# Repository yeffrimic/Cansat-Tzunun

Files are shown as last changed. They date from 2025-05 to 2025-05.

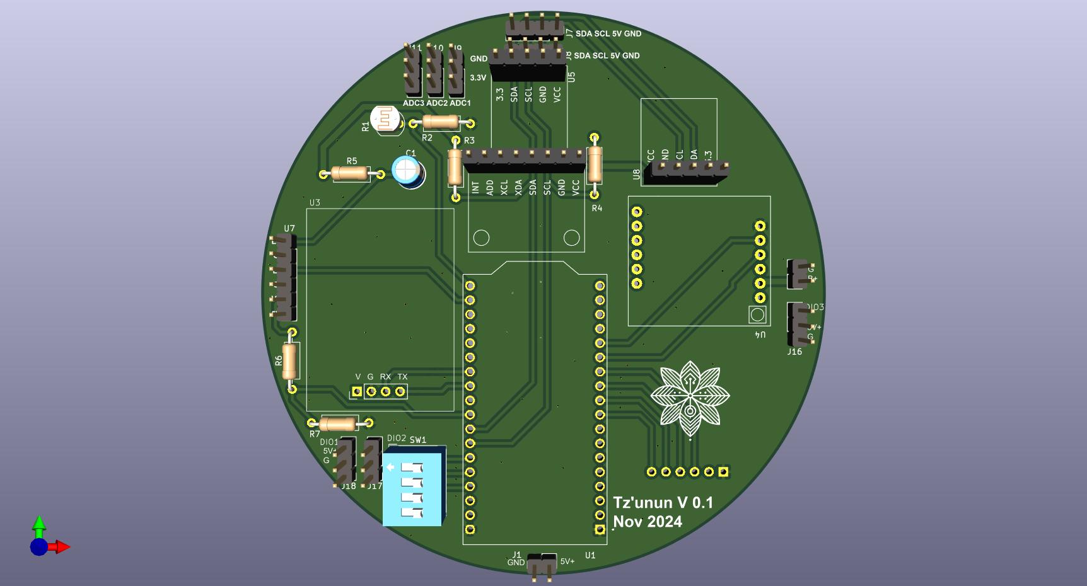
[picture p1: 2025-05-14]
kicad/frente.jpg

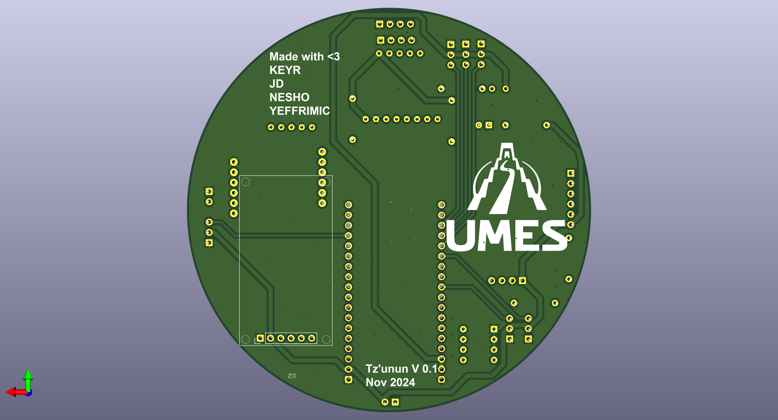
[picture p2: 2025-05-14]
kicad/back.png

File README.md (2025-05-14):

# 🌎 Estación de Calidad del Aire – Proyecto CanSat Tzunun

Este repositorio contiene el código, documentación, archivos de diseño y recursos educativos para implementar una **estación de monitoreo ambiental**, así como su versión miniaturizada adaptada al formato **CanSat**. El proyecto fue desarrollado por estudiantes de la **Universidad Mesoamericana, sede Quetzaltenango**, como una herramienta de medición ambiental portátil, educativa y de bajo costo.

---

## 🚀 Guía de Instalación – Heltec WiFi LoRa 32 (V3) en Arduino IDE

### Paso 1: Instalar el Arduino IDE
Descarga e instala la versión más reciente desde: [https://www.arduino.cc/en/software](https://www.arduino.cc/en/software)

### Paso 2: Añadir URL del Gestor de Placas
1. Abre Arduino IDE.
2. Ve a **Archivo → Preferencias**.
3. En **"Gestor de URLs adicionales de tarjetas"**, añade: https://resource.heltec.cn/download/package_heltec_esp32_index.json
### Paso 3: Instalar el soporte para Heltec
1. Ve a **Herramientas → Placa → Gestor de tarjetas**.
2. Busca **Heltec ESP32** y haz clic en *Instalar*.

### Paso 4: Seleccionar la placa correcta
1. En **Herramientas → Placa**, selecciona:  
**Heltec WiFi LoRa 32 (V3)**.
2. Configura:
- Flash Frequency: 80 MHz  
- Upload Speed: 115200  
- Partition Scheme: Default 4MB with spiffs

### Paso 5: Instalar librerías necesarias
Desde el **Gestor de Librerías**, instala:
- `Wire.h`
- `Adafruit BMP085`
- `AHTxx`
- `LoRa.h`
- `SD.h`
- `U8g2`
- Y las indicadas en la carpeta `codigo/`

---

## 📌 Descripción del Proyecto

La estación mide:
- Temperatura y humedad
- Presión atmosférica
- Gases y partículas
- Aceleración y orientación (para CanSat)
- GPS (en versiones avanzadas)

### Versiones:
- **Estación Fija:** Para instalación permanente.
- **CanSat:** Miniatura para lanzamientos simulados.

Ambas versiones transmiten datos por **LoRa/WiFi** y se visualizan con **Node-RED**.

---

## 🧠 Estructura del Repositorio

├── codigo/ # Códigos para Heltec ESP32 Lora V3

├── modelos_3d/ # Archivos STL para impresión 3D

├── node-red/ # Flujos exportados de Node-RED

├── kicad/ # Archivos del diseño PCB en KiCad

### Contenido detallado

#### `codigo/`
- Lectura de sensores
- Comunicación LoRa/WiFi
- Escritura en SD
- Pantalla OLED

#### `modelos_3d/`
- Archivos STL para impresión FDM
- Versiones fija y CanSat

#### `node-red/`
- Dashboards
- Descarga de datos (CSV, JSON)
- Endpoints y APIs

#### `kicad/`
- Archivos `.kicad_pcb`, `.sch`, `.kicad_pro`
- Gerbers, BOM y diagramas

#### `videos/`
- Armado y soldadura
- Carga de código
- Uso de Node-RED
- Diagnóstico

---

## 🧩 Hardware Utilizado

Diseño PCB en **KiCad**, optimizado para **JLCPCB** con diámetro de 10 cm.

### Componentes:
- Heltec WiFi LoRa 32 V3 (ESP32)
- GPS
- MPU6050
- BMP180
- AHT10
- Módulo GSM
- Sensor de partículas
- Conectores de expansión
- Pantalla OLED

---

## 🌐 Plataforma Node-RED

- Visualización en tiempo real
- Descarga de históricos
- Redireccionamiento automático
- Endpoints personalizados

Instalable en Raspberry Pi, PC o nube.

---

## ✅ Requisitos

- Arduino IDE
- Librerías para sensores (ver `codigo/`)
- Node-RED
- KiCad 7.x
- Fuente 5V 1A
- microSD (<8 GB) para CanSat

---

## 📄 Licencia

Este proyecto está bajo la Licencia **MIT**.  
Puedes usarlo, modificarlo y compartirlo libremente con los créditos correspondientes.

---

## 👨‍🏫 Créditos

**Universidad Mesoamericana** – Facultad de Ingeniería  
**Proyecto CanSat Tzunun 2024** – Sede Quetzaltenango  
Docente responsable: *[Nombre del asesor]*

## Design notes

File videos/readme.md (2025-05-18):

Link de los videos en google drive. 
https://drive.google.com/drive/folders/1fE3G5Yh2EopbgKv5OzK_qw8cplDIR1OE?usp=sharing

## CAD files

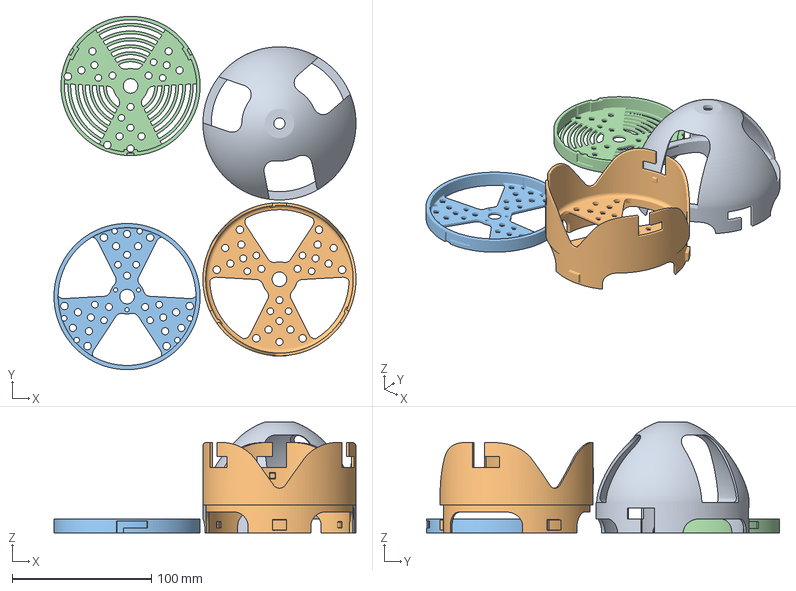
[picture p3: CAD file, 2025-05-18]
3d/Diseño_Cansat.3mf
217.0 x 253.8 x 79.7 mm
Cuerpo1 x 2
Cuerpo3
Cuerpo4

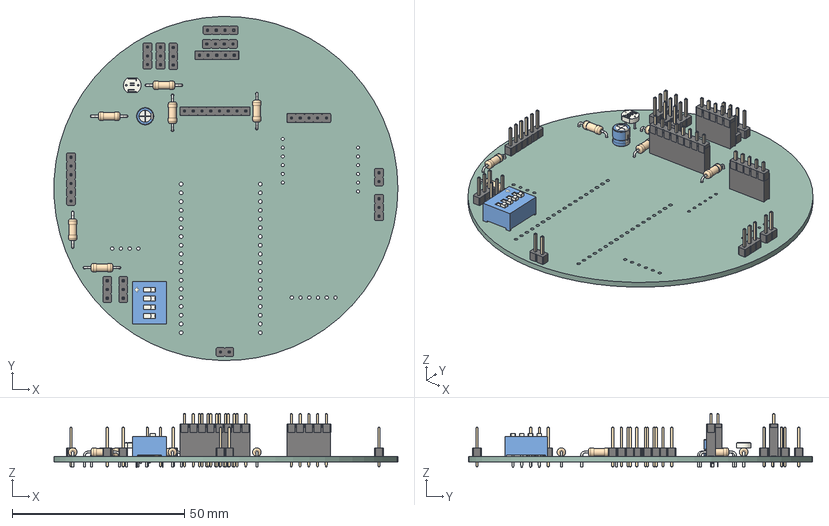
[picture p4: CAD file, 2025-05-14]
kicad/cansat.step
99.9 x 100.0 x 15.7 mm
PinSocket_1x05_P2.54mm_Vertical x 2
PinHeader_1x05_P254mm_Vertical x 2
PinHeader_1x03_P254mm_Vertical x 6
SW_DIP_SPSTx04_Slide_978x1234mm_W762mm_P254mm
R_Axial_DIN0207_L63mm_D25mm_P1016mm_Horizontal x 6
PinHeader_1x06_P254mm_Vertical
PinHeader_1x08_P254mm_Vertical
PinSocket_1x08_P2.54mm_Vertical
PinHeader_1x02_P254mm_Vertical x 2
CP_Radial_D50mm_P250mm
PinHeader_1x04_P254mm_Vertical x 2
R_LDR_5.1x4.3mm_P3.4mm_Vertical
cansat_PCB

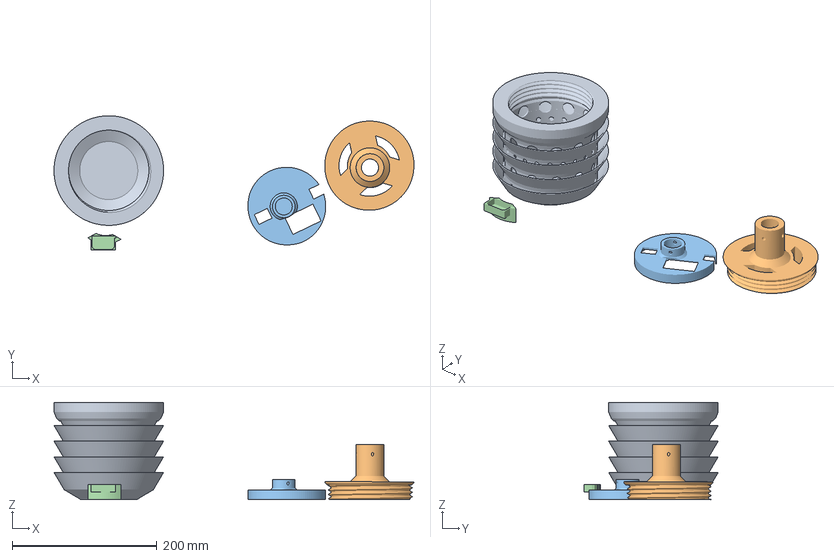
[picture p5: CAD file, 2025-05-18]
3d/Estacion_Meteorologica.3mf
497.8 x 185.9 x 134.1 mm
Cuerpo73
Cuerpo77_A
Base_Placa
Cuerpo92

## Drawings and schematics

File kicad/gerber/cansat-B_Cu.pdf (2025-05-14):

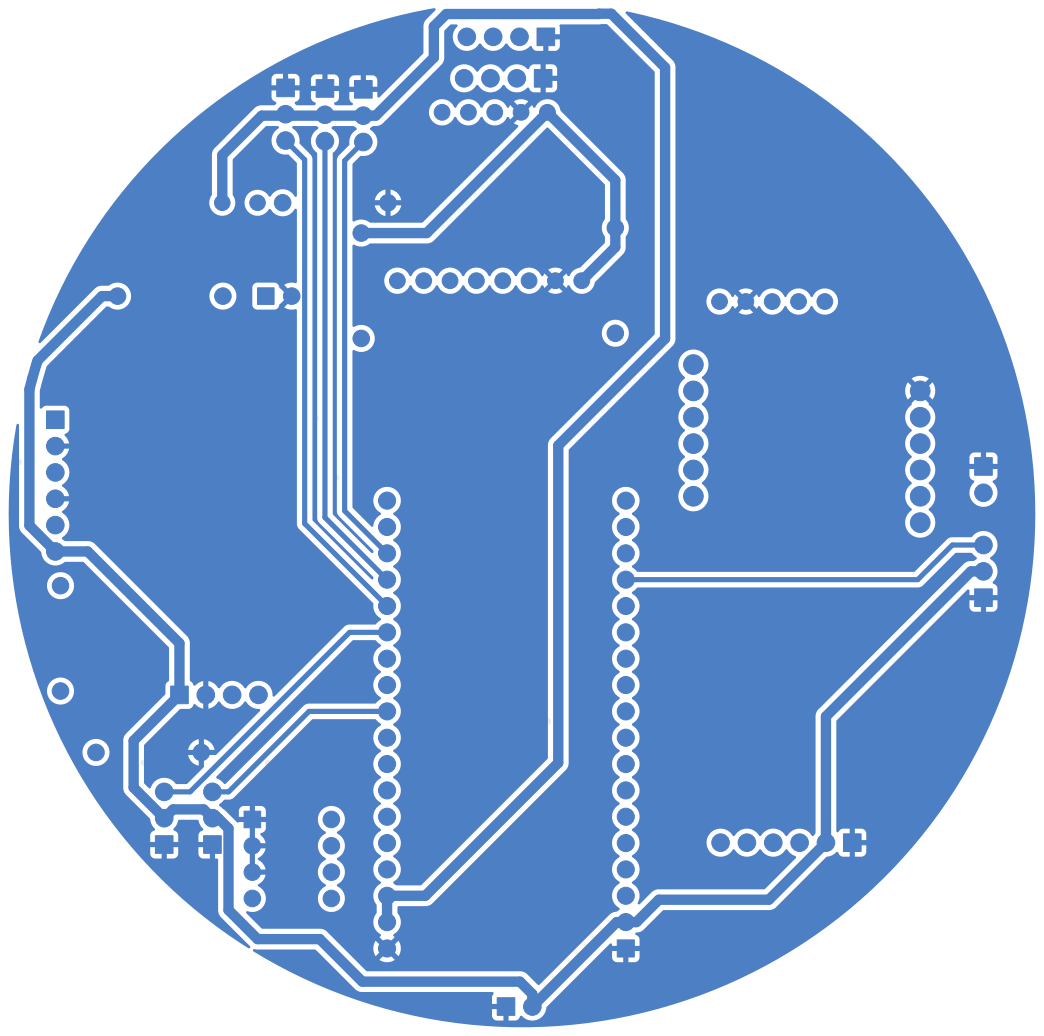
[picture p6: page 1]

Id: 1/1 Title: File: cansat.kicad_pcb Sheet:

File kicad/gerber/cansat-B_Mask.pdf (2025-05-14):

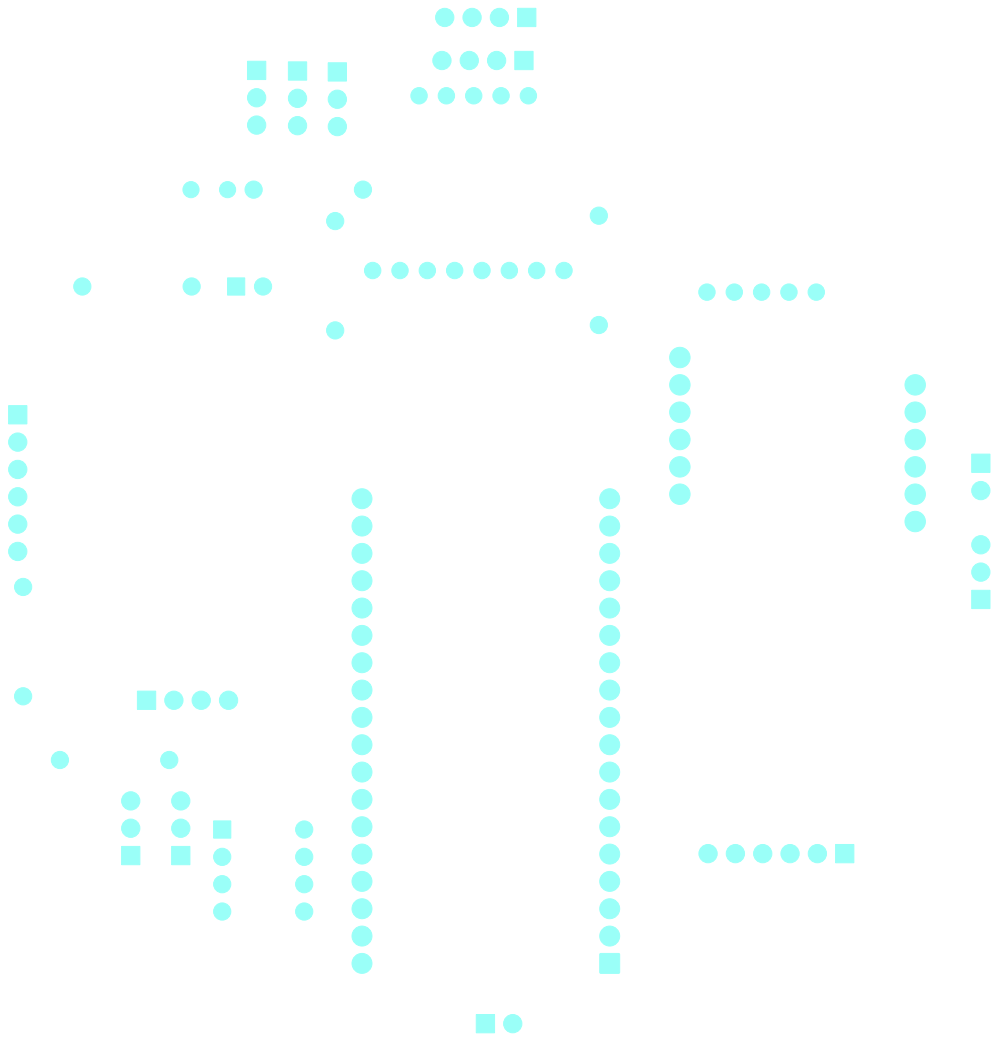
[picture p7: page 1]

Id: 1/1 Title: File: cansat.kicad_pcb Sheet:

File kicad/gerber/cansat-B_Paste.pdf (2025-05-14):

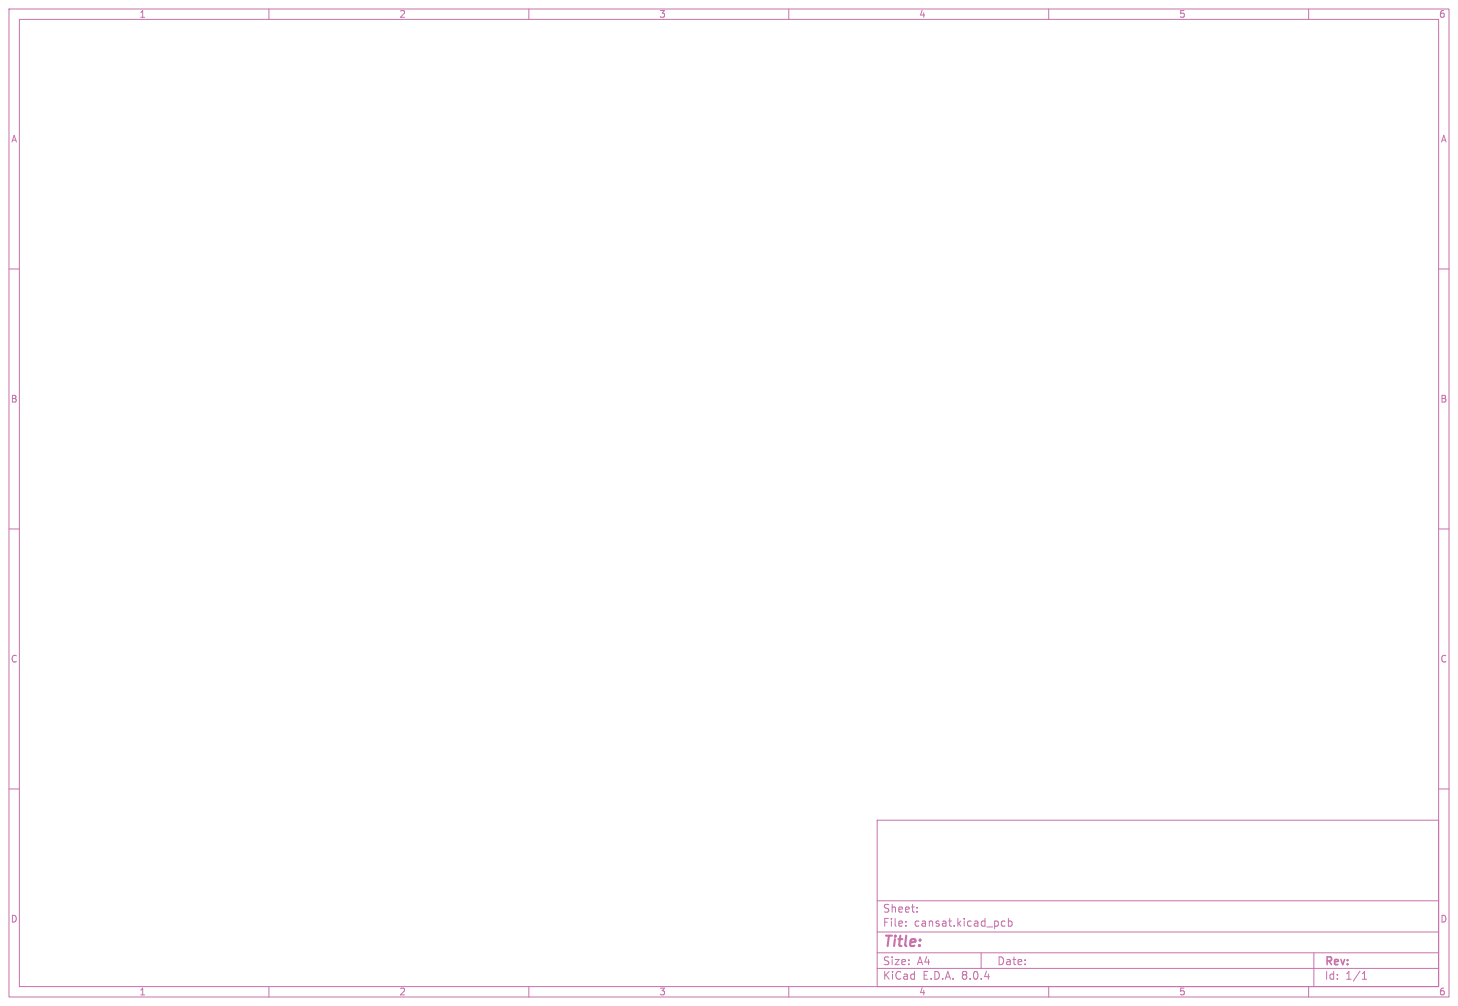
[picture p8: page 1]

Id: 1/1 Title: File: cansat.kicad_pcb Sheet:

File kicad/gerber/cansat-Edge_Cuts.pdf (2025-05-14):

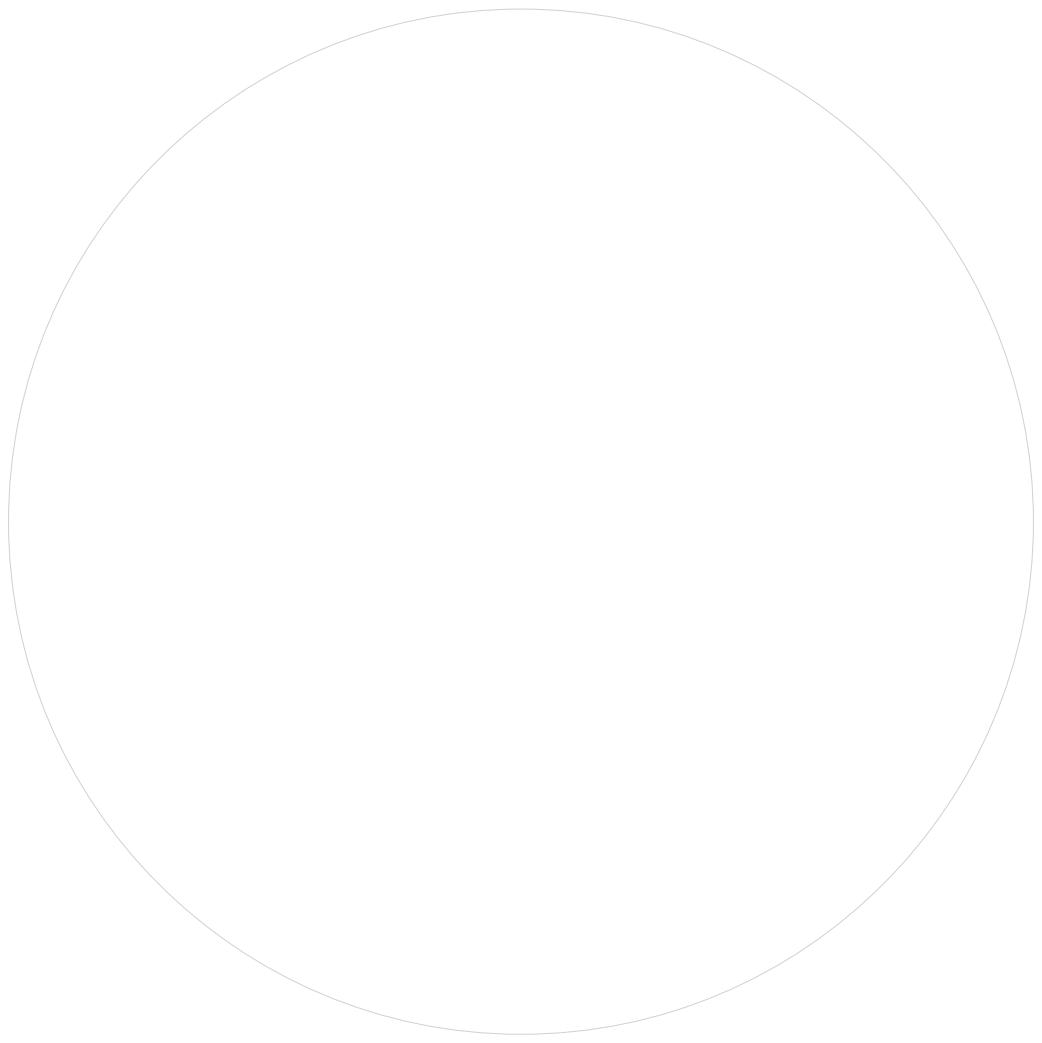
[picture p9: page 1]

Id: 1/1 Title: File: cansat.kicad_pcb Sheet:

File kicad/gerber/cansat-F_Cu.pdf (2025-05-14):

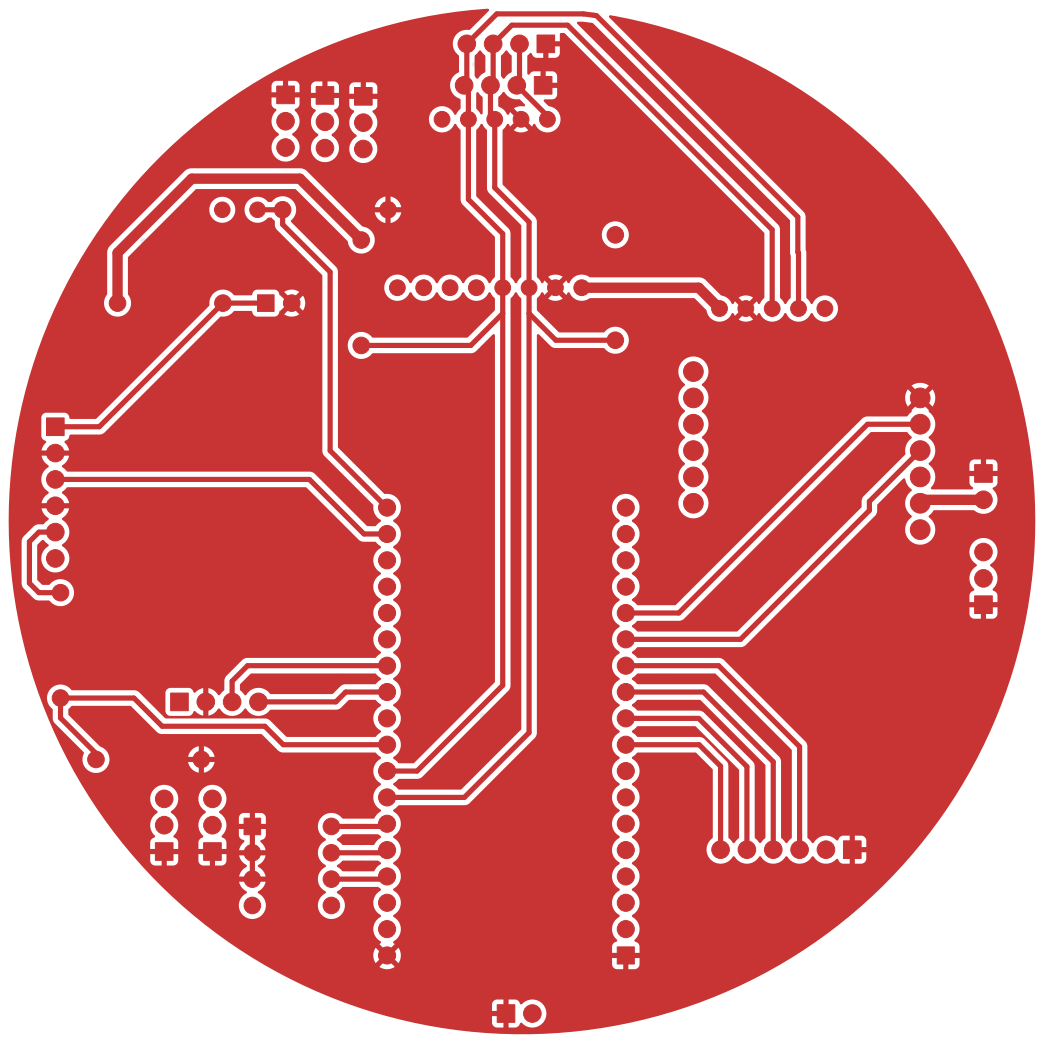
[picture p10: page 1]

Id: 1/1 Title: File: cansat.kicad_pcb Sheet:

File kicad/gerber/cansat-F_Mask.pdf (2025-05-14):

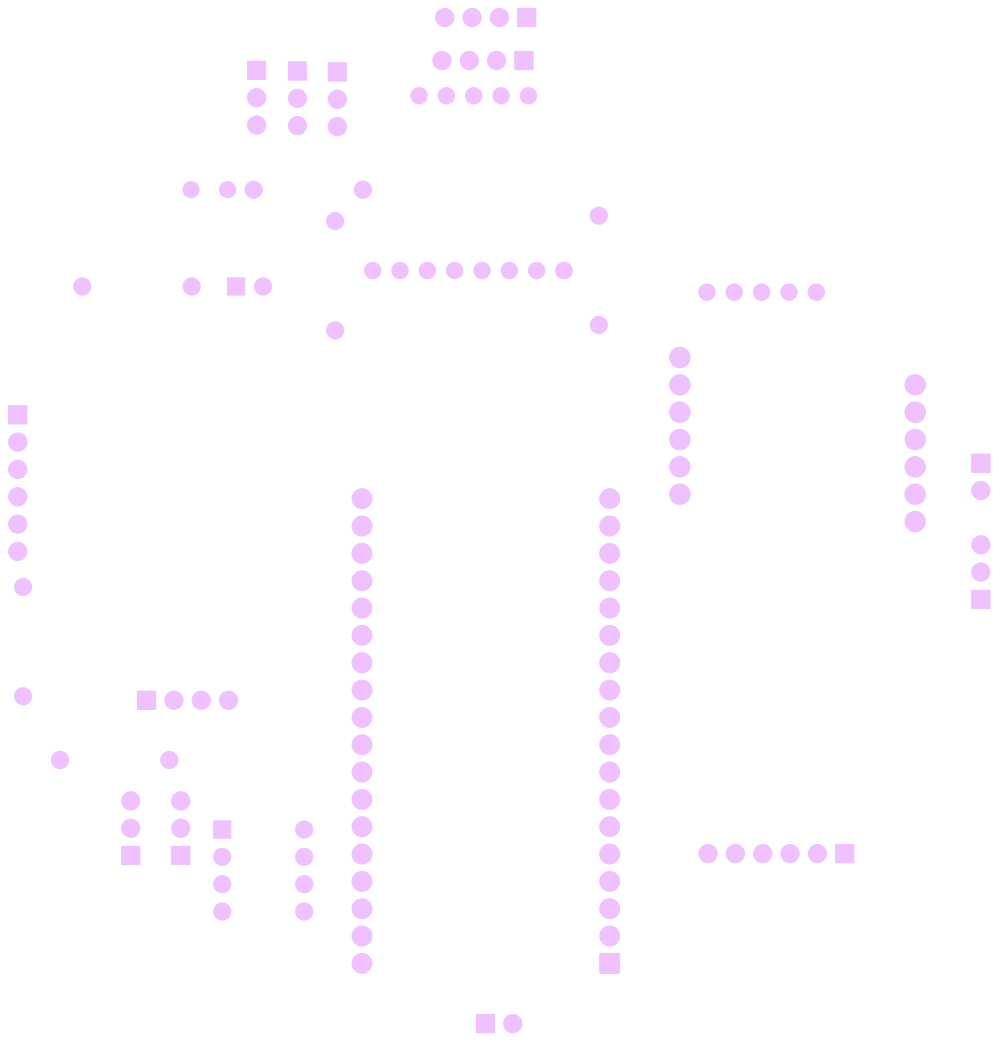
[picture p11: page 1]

Id: 1/1 Title: File: cansat.kicad_pcb Sheet:

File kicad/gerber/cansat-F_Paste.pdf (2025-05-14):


Id: 1/1 Title: File: cansat.kicad_pcb Sheet:

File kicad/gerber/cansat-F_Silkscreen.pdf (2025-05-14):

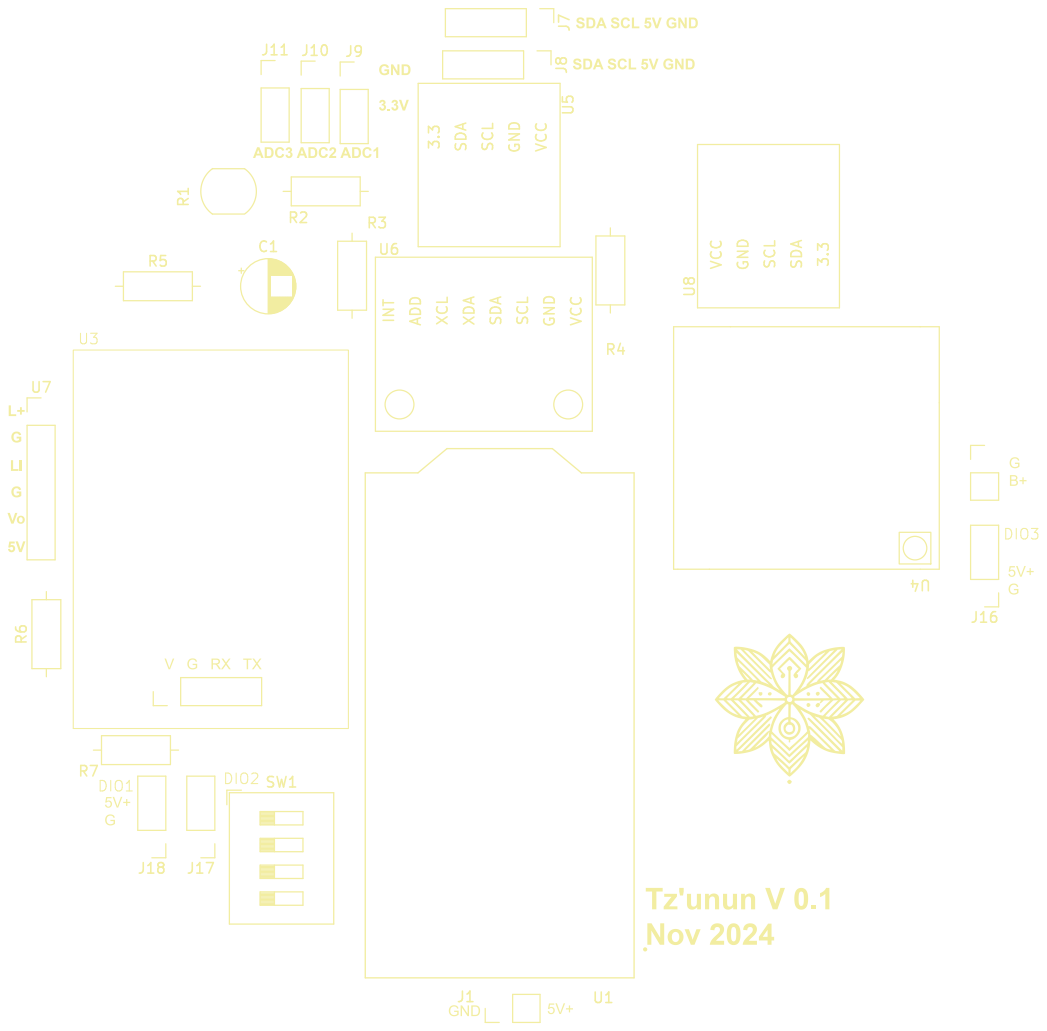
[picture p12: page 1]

U6INT ADD XCL XDA SDA SCL GND VCC

Id: 1/1 Title: File: cansat.kicad_pcb Sheet:

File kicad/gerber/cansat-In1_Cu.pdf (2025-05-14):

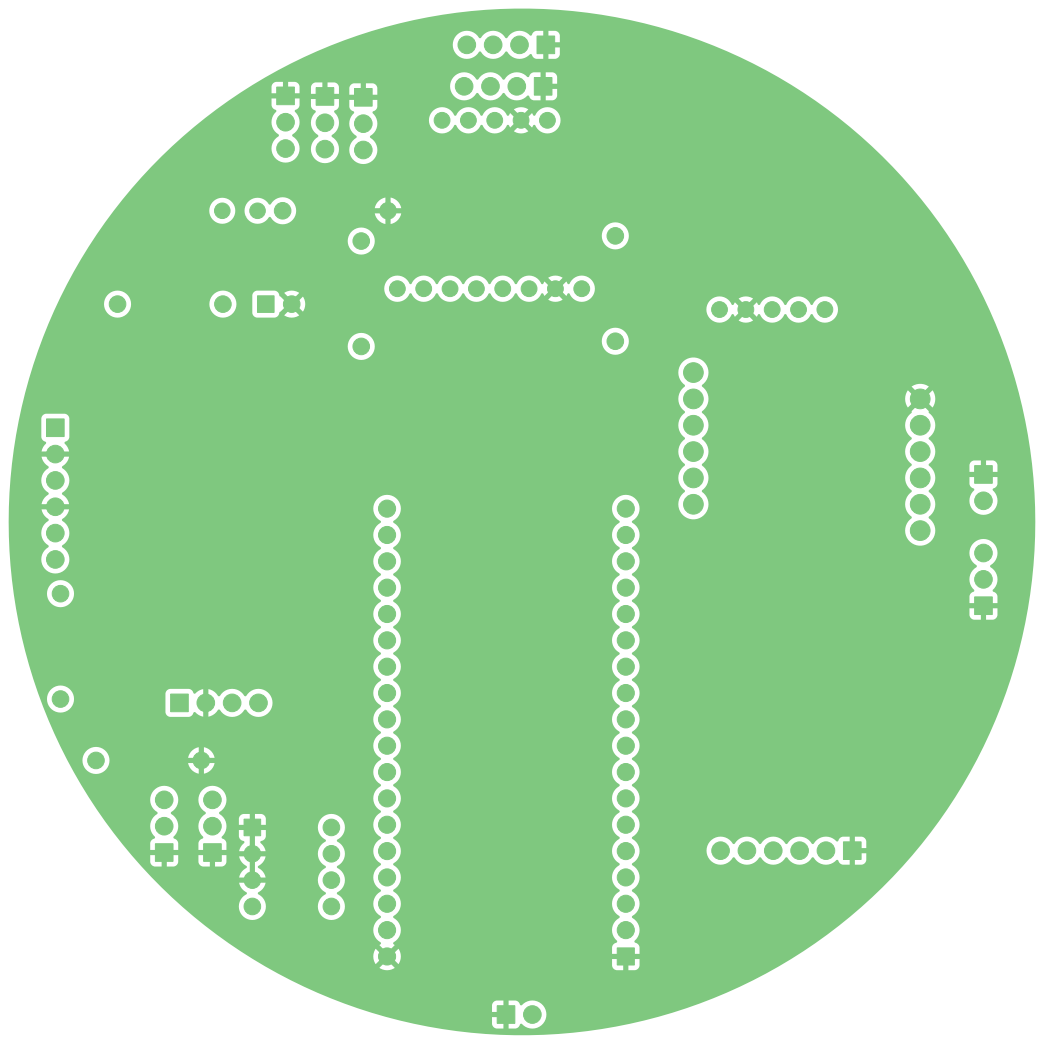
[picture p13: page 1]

Id: 1/1 Title: File: cansat.kicad_pcb Sheet:

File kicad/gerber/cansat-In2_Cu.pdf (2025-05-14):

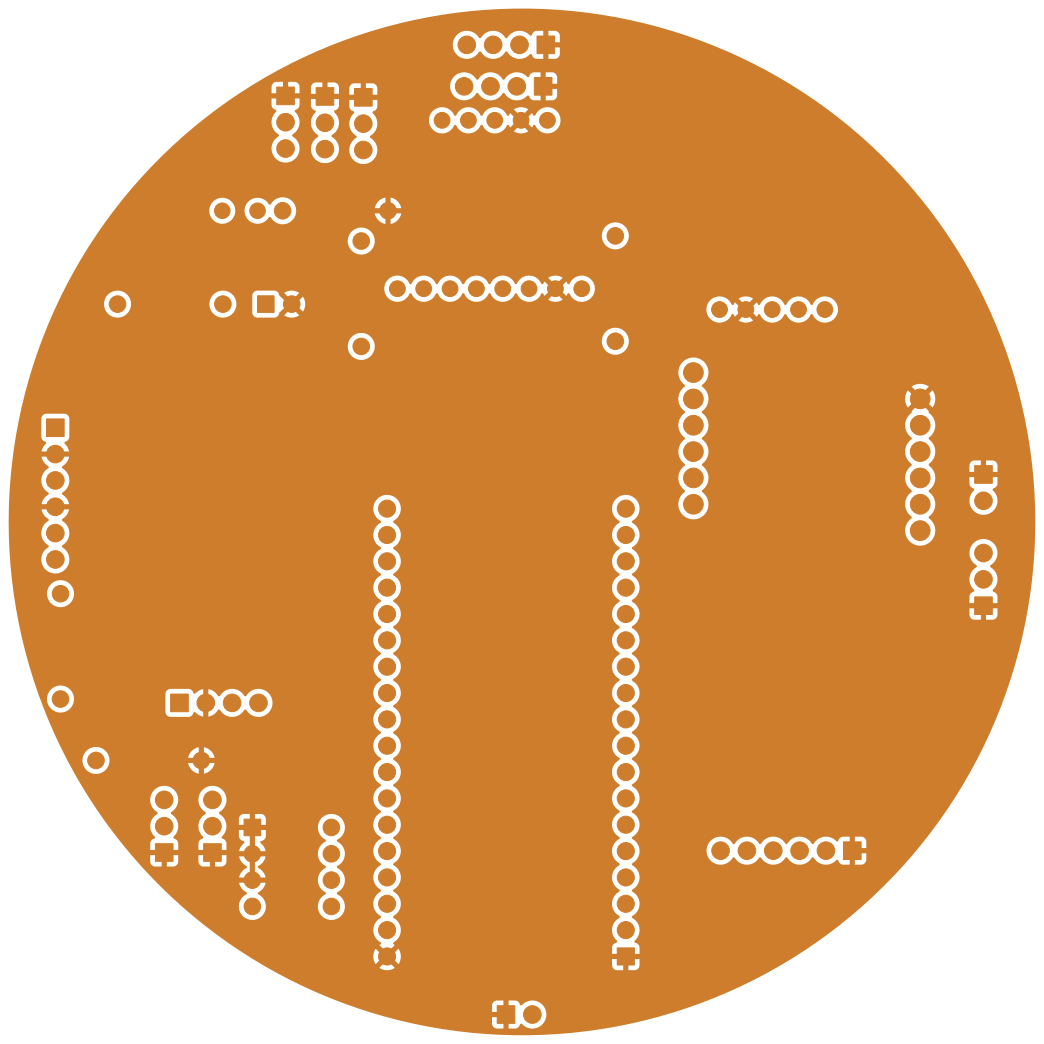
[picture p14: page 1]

Id: 1/1 Title: File: cansat.kicad_pcb Sheet:

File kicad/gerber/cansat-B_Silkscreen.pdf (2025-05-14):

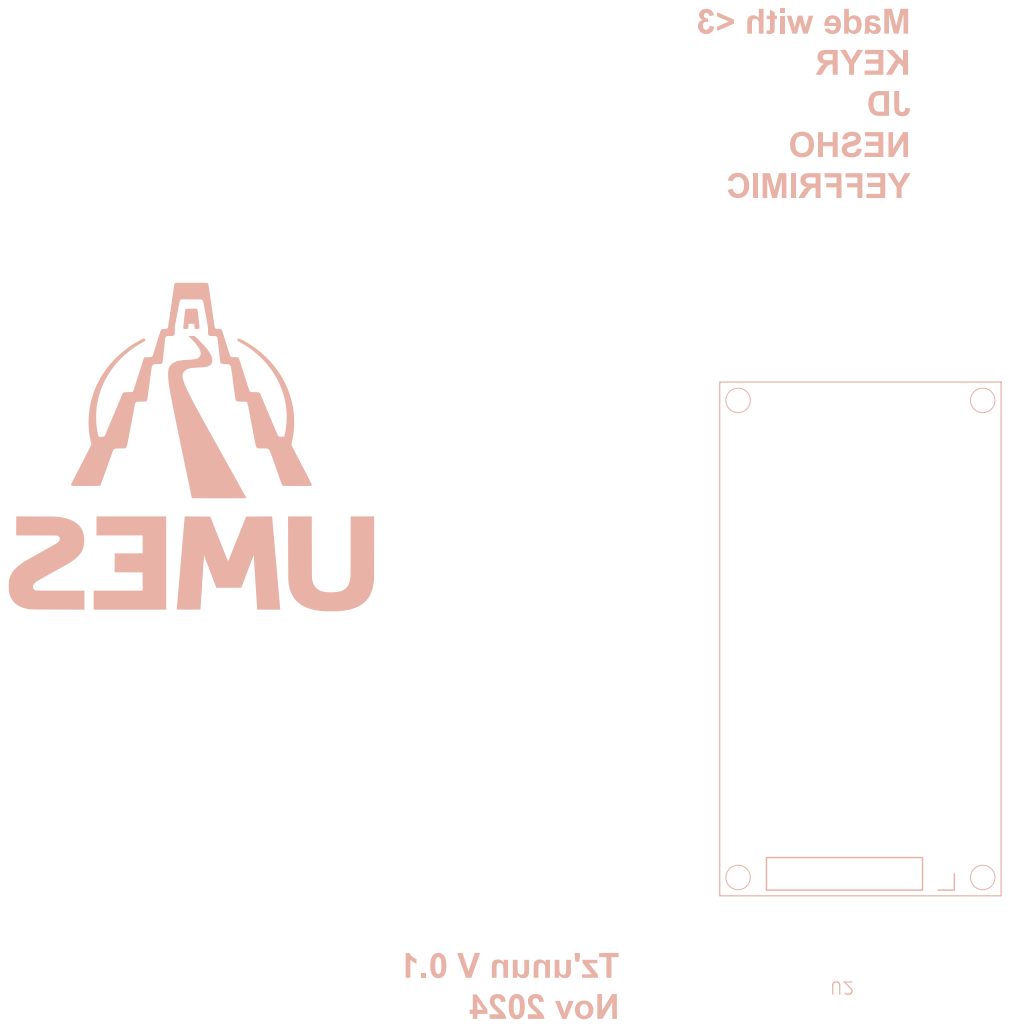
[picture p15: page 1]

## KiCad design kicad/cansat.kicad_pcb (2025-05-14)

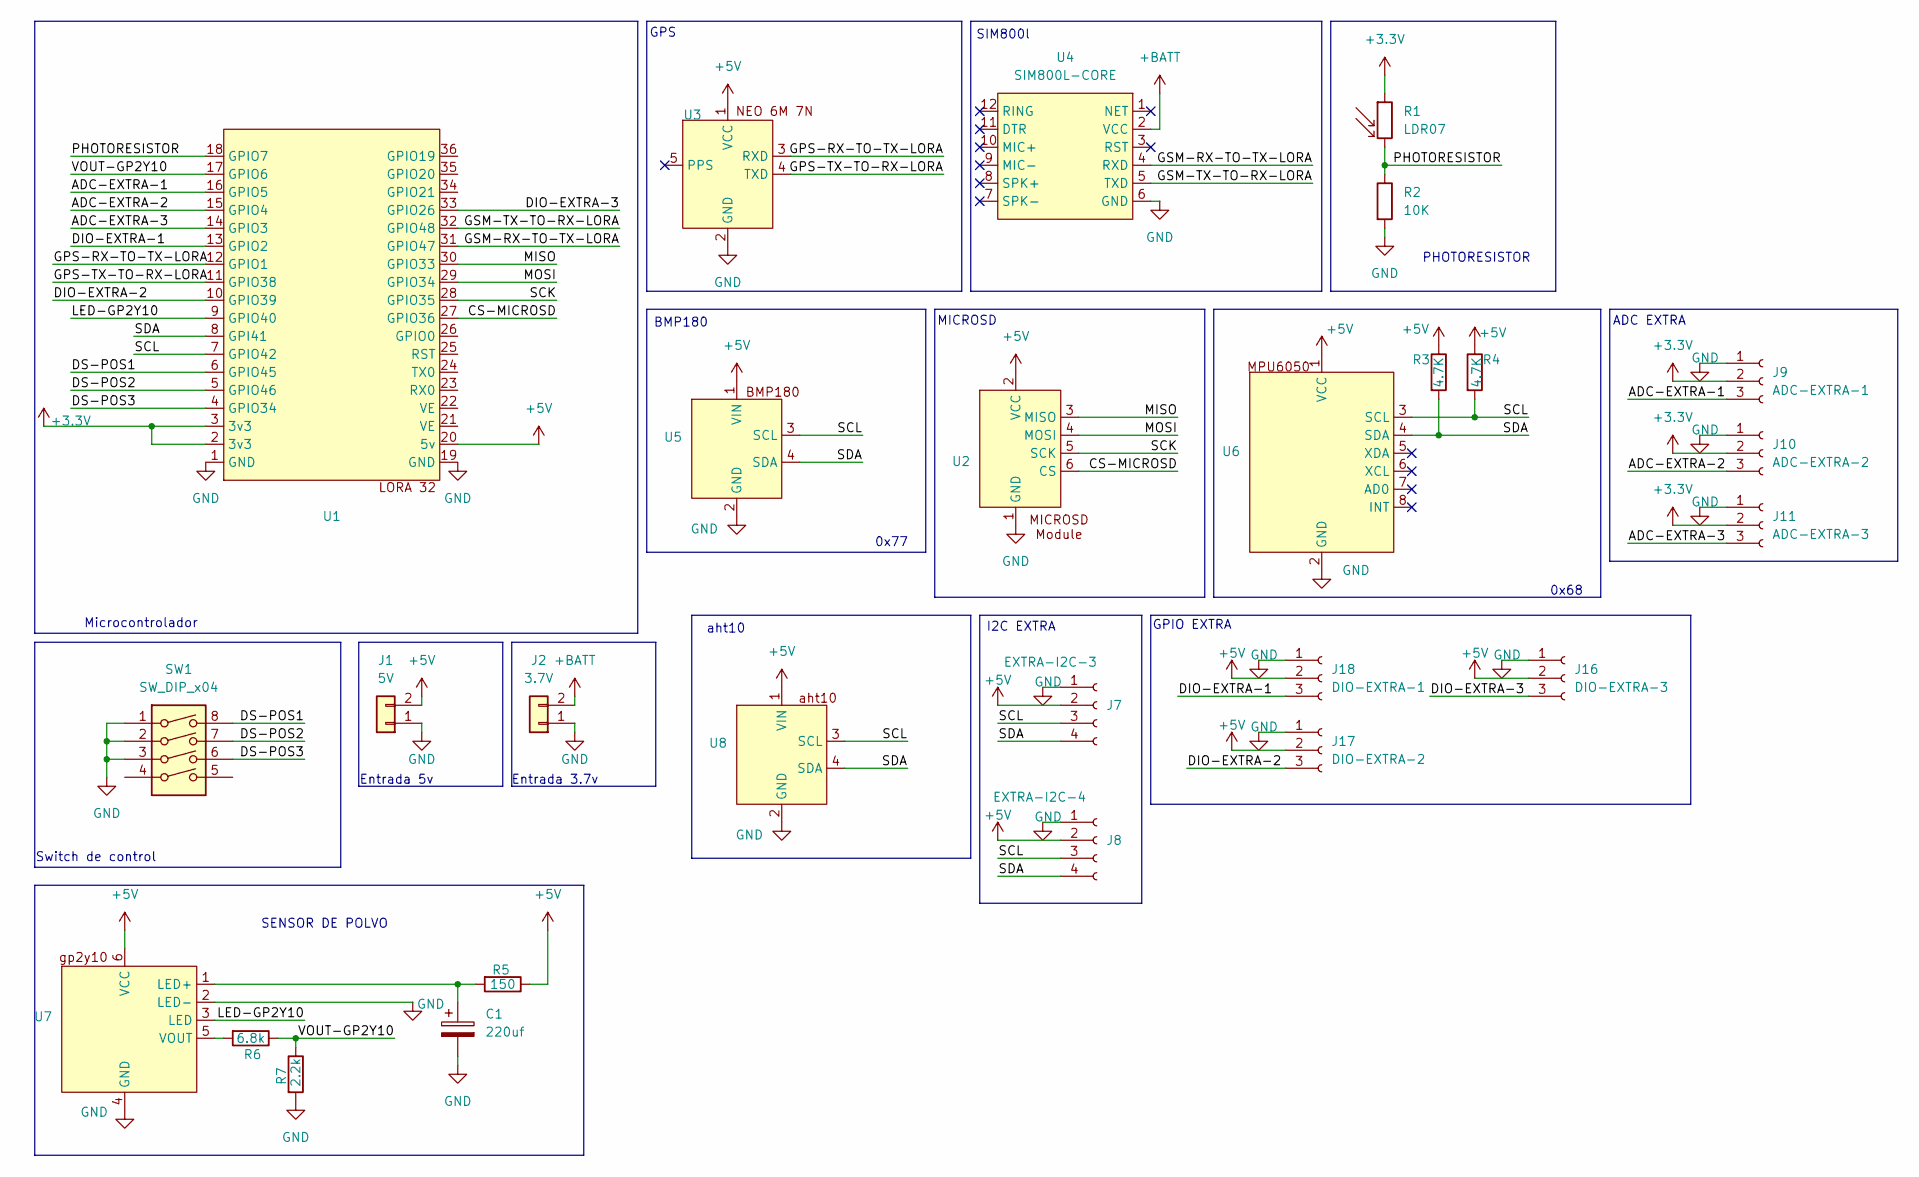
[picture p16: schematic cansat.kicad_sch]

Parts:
C1: 220uf; CP_Radial_D5.0mm_P2.50mm
J1: 5V; PinHeader_1x02_P2.54mm_Vertical
J2: 3.7V; PinHeader_1x02_P2.54mm_Vertical
J7: EXTRA-I2C-3; PinHeader_1x04_P2.54mm_Vertical
J8: EXTRA-I2C-4; PinHeader_1x04_P2.54mm_Vertical
J9: ADC-EXTRA-1; PinHeader_1x03_P2.54mm_Vertical
J10: ADC-EXTRA-2; PinHeader_1x03_P2.54mm_Vertical
J11: ADC-EXTRA-3; PinHeader_1x03_P2.54mm_Vertical
J16: DIO-EXTRA-3; PinHeader_1x03_P2.54mm_Vertical
J17: DIO-EXTRA-2; PinHeader_1x03_P2.54mm_Vertical
J18: DIO-EXTRA-1; PinHeader_1x03_P2.54mm_Vertical
R1: LDR07; R_LDR_5.1x4.3mm_P3.4mm_Vertical
R2: 10K; R_Axial_DIN0207_L6.3mm_D2.5mm_P10.16mm_Horizontal
R3, R4: 4.7K; R_Axial_DIN0207_L6.3mm_D2.5mm_P10.16mm_Horizontal
R5: 150; R_Axial_DIN0207_L6.3mm_D2.5mm_P10.16mm_Horizontal
R6: 6.8k; R_Axial_DIN0207_L6.3mm_D2.5mm_P10.16mm_Horizontal
R7: 2.2k; R_Axial_DIN0207_L6.3mm_D2.5mm_P10.16mm_Horizontal
SW1: SW_DIP_x04; SW_DIP_SPSTx04_Slide_9.78x12.34mm_W7.62mm_P2.54mm
U1: MODULE_WIFI_KIT_32__V3_
U2: micro sd
U3: neo6 gps module
U4: SIM800L-CORE
U5, U8: module_bmp180
U6: module_mpu6050
U7: PinHeader_1x06_P2.54mm_Vertical

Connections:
+3.3V: J9.2, J10.2, J11.2, R1.1, U1.2 (3v3), U1.3 (3v3)
+5V: J1.2, J7.2, J8.2, J16.2, J17.2, J18.2, R3.1, R4.1, R5.1, U1.20 (5v), U2.2 (VCC), U3.1 (VCC), U5.1 (VIN), U6.1 (VCC), U7.6 (VCC), U8.1 (VIN)
+BATT: J2.2, U4.2 (VCC)
/ADC-EXTRA-1: J9.3, U1.16 (GPIO5)
/ADC-EXTRA-2: J10.3, U1.15 (GPIO4)
/ADC-EXTRA-3: J11.3, U1.14 (GPIO3)
/CS-MICROSD: U1.27 (GPIO36), U2.6 (CS)
/DIO-EXTRA-1: J18.3, U1.13 (GPIO2)
/DIO-EXTRA-2: J17.3, U1.10 (GPIO39)
/DIO-EXTRA-3: J16.3, U1.33 (GPIO26)
/DS-POS1: SW1.8, U1.6 (GPIO45)
/DS-POS2: SW1.7, U1.5 (GPIO46)
/DS-POS3: SW1.6, U1.4 (GPIO34)
/GPS-RX-TO-TX-LORA: U1.12 (GPIO1), U3.3 (RXD)
/GPS-TX-TO-RX-LORA: U1.11 (GPIO38), U3.4 (TXD)
/GSM-RX-TO-TX-LORA: U1.31 (GPIO47), U4.4 (RXD)
/GSM-TX-TO-RX-LORA: U1.32 (GPIO48), U4.5 (TXD)
/LED-GP2Y10: U1.9 (GPIO40), U7.3 (LED)
/MISO: U1.30 (GPIO33), U2.3 (MISO)
/MOSI: U1.29 (GPIO34), U2.4 (MOSI)
/PHOTORESISTOR: R1.2, R2.1, U1.18 (GPIO7)
/SCK: U1.28 (GPIO35), U2.5 (SCK)
/SCL: J7.3, J8.3, R4.2, U1.7 (GPIO42), U5.3 (SCL), U6.3 (SCL), U8.3 (SCL)
/SDA: J7.4, J8.4, R3.2, U1.8 (GPI41), U5.4 (SDA), U6.4 (SDA), U8.4 (SDA)
/VOUT-GP2Y10: R6.1, R7.1, U1.17 (GPIO6)
GND: C1.2, J1.1, J2.1, J7.1, J8.1, J9.1, J10.1, J11.1, J16.1, J17.1, J18.1, R2.2, R7.2, SW1.1, SW1.2, SW1.3, U1.1 (GND), U1.19 (GND), U2.1 (GND), U3.2 (GND), U4.6 (GND), U5.2 (GND), U6.2 (GND), U7.2 (LED-), U7.4 (GND), U8.2 (GND)
unnamed: C1.1, R5.2, U7.1 (LED+)
unnamed: R6.2, U7.5 (VOUT)

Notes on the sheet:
SIM800l
ADC EXTRA
Switch de control
PHOTORESISTOR
aht10
SENSOR DE POLVO
0x77
BMP180
Entrada 5v
GPS
GPIO EXTRA
0x68
Entrada 3.7v
I2C EXTRA
Microcontrolador
MICROSD

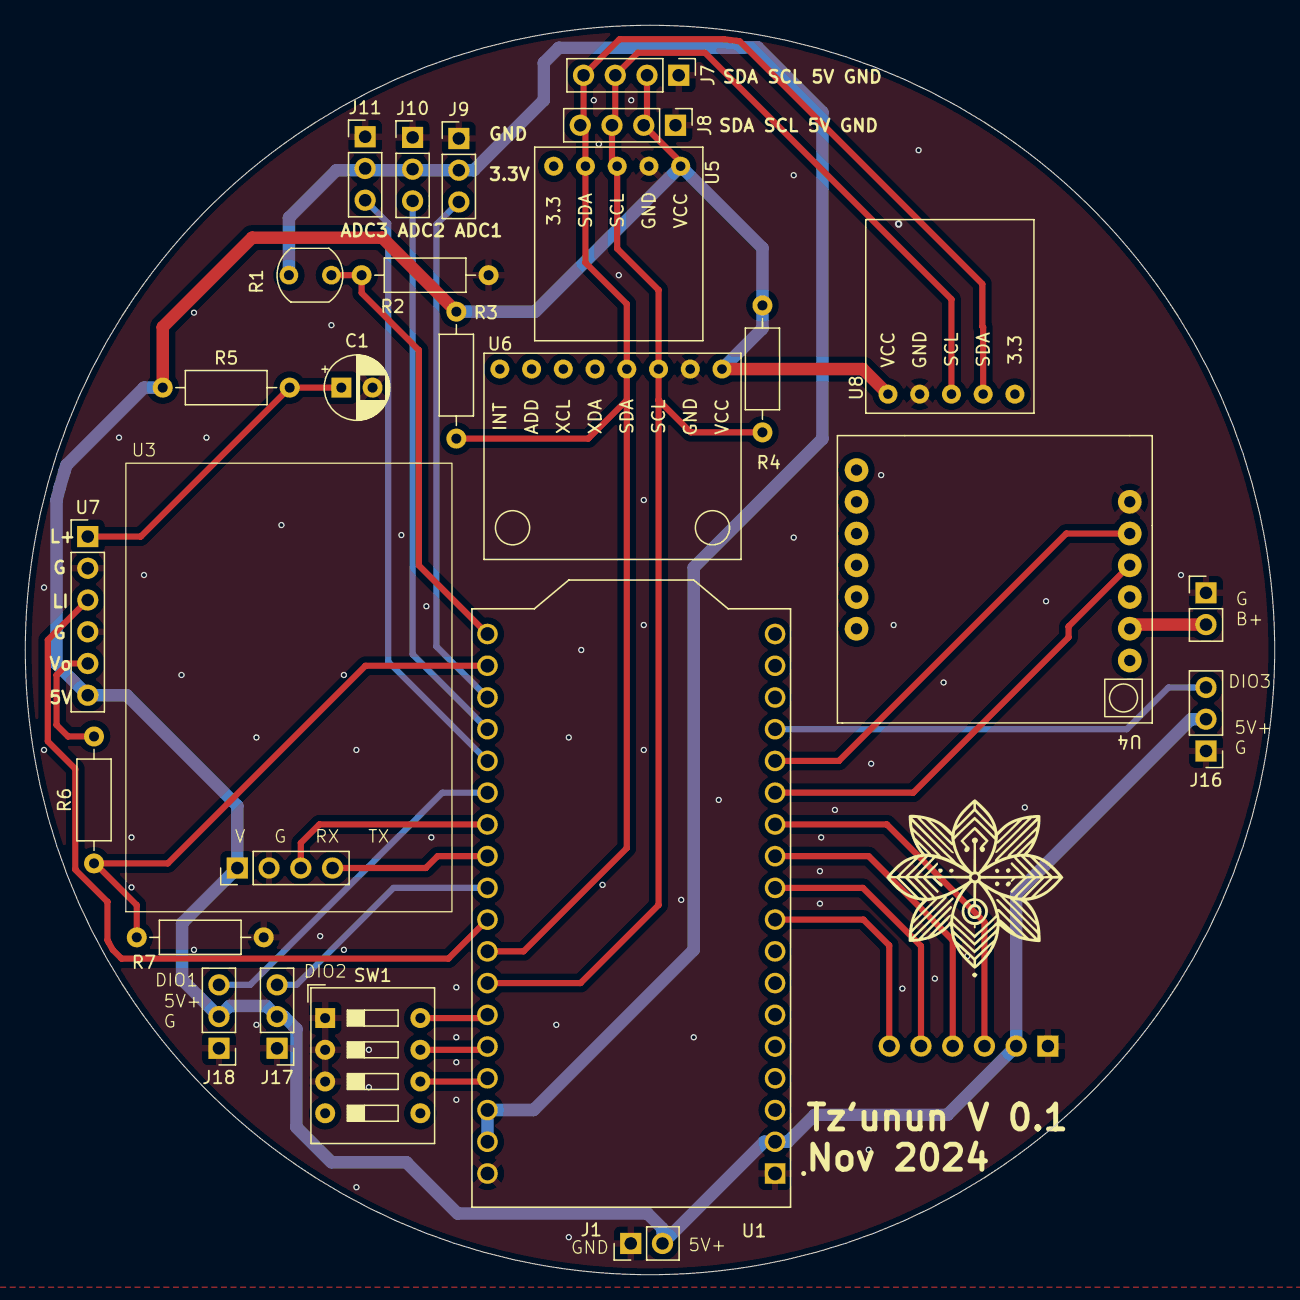
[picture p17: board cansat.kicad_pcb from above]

Board: 4 copper layers, 100.0 x 100.0 mm, 27 parts (1 on the bottom side), 28 nets.

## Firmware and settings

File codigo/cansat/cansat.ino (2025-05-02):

#include "FS.h"
#include "SD.h"
#include "SPI.h"
#include <Wire.h>
#include <Adafruit_BMP085.h>
#include <Adafruit_AHTX0.h>
#include <Adafruit_MPU6050.h>
#include <GP2YDustSensor.h>
#include <WiFi.h>
#include <PubSubClient.h>

#define MQTT_VERSION MQTT_VERSION_3_1_1
#define REASSIGN_PINS
int sck = 35;
int miso = 33;
int mosi = 34;
int cs = 36;

unsigned long previousMillis = 0;
const long interval = 1000;  // Aumentar el intervalo a 5 segundos

const uint8_t SHARP_LED_PIN = 6;
const uint8_t SHARP_VO_PIN = A3;

const char* ssid = "Xibalba Hackerspace";
const char* password = "ESTALIBRE";

const char* mqtt_server = "broker.hivemq.com";
const char* mqtt_topic = "/cansat/umes/mision";
char mqtt_client_id[20];

WiFiClient espClient;
PubSubClient client(espClient);

Adafruit_BMP085 bmp;
Adafruit_AHTX0 aht;
Adafruit_MPU6050 mpu;
GP2YDustSensor dustSensor(GP2YDustSensorType::GP2Y1014AU0F, SHARP_LED_PIN, SHARP_VO_PIN);

const float BMP_TEMP_MIN = -20.0;
const float BMP_TEMP_MAX = 85.0;
const float PRESSURE_MIN = 500.0;
const float PRESSURE_MAX = 900.0;
const float ALTITUDE_MIN = -200.0;
const float ALTITUDE_MAX = 5000.0;
const float AHT_TEMP_MIN = -40.0;
const float AHT_TEMP_MAX = 85.0;
const float HUMIDITY_MIN = 0.0;
const float HUMIDITY_MAX = 100.0;
const float ACCEL_MIN = -16.0;
const float ACCEL_MAX = 16.0;
const float DUST_DENSITY_MIN = 0.0;
const float DUST_DENSITY_MAX = 500.0;

float bmpTemperature = 0.0;
float pressure = 0.0;
float altitude = 0.0;
float ahtTemperature = 0.0;
float ahtHumidity = 0.0;
float accelX = 0.0;
float accelY = 0.0;
float accelZ = 0.0;
float dustDensity = 0.0;

void setup_wifi() {
  delay(10);
  Serial.println();
  Serial.print("Conectando a ");
  Serial.println(ssid);

  WiFi.begin(ssid, password);

  while (WiFi.status() != WL_CONNECTED) {
    delay(500);
    Serial.print(".");
  }

  Serial.println("\nWiFi conectado");
  Serial.print("Dirección IP: ");
  Serial.println(WiFi.localIP());
}

void reconnect() {
  snprintf(mqtt_client_id, sizeof(mqtt_client_id), "cansat%d", random(0, 9999));
  Serial.println(mqtt_client_id);
  while (!client.connected()) {
    Serial.print("Intentando conectar al broker MQTT...");
    if (client.connect(mqtt_client_id)) {
      Serial.println("conectado");
    } else {
      Serial.print("falló, rc=");
      Serial.print(client.state());
      Serial.println(" intentando de nuevo en 5 segundos");
      delay(5000);
    }
  }
}

bool validateSensorValue(float value, float minValue, float maxValue) {
  return (value >= minValue && value <= maxValue);
}

void setup() {
  Serial.begin(115200);

  //SPI.begin(sck, miso, mosi, cs);
/*
  if (!SD.begin(cs)) {
    Serial.println("Error al montar la tarjeta SD");
    return;
  }
*/
  if (!bmp.begin()) {
    Serial.println("BMP180 no detectado");
    return;
  }

  if (!aht.begin()) {
    Serial.println("AHT10 no detectado");
    return;
  }
/*
  if (!mpu.begin()) {
    Serial.println("MPU6050 no detectado");
    return;
  }
  */

  dustSensor.begin();

  setup_wifi();

  client.setServer(mqtt_server, 1883);

  Serial.println("Sensores inicializados correctamente");
}

void loop() {
  if (!client.connected()) {
    reconnect();
  }
  client.loop();

  unsigned long currentMillis = millis();

  if (currentMillis - previousMillis >= interval) {
    previousMillis = currentMillis;

    float newBmpTemperature = bmp.readTemperature();
    float newPressure = bmp.readPressure() / 100.0F;
    float newAltitude = bmp.readAltitude();

    sensors_event_t humidity, temp;
    aht.getEvent(&humidity, &temp);
    float newAhtTemperature = temp.temperature;
    float newAhtHumidity = humidity.relative_humidity;
/*
    sensors_event_t accel, gyro, mpuTemp;
    mpu.getEvent(&accel, &gyro, &mpuTemp);
    float newAccelX = accel.acceleration.x;
    float newAccelY = accel.acceleration.y;
    float newAccelZ = accel.acceleration.z;
*/
    float newDustDensity = dustSensor.getDustDensity();

    if (validateSensorValue(newBmpTemperature, BMP_TEMP_MIN, BMP_TEMP_MAX)) {
      bmpTemperature = newBmpTemperature;
    }
    if (validateSensorValue(newPressure, PRESSURE_MIN, PRESSURE_MAX)) {
      pressure = newPressure;
    }
    if (validateSensorValue(newAltitude, ALTITUDE_MIN, ALTITUDE_MAX)) {
      altitude = newAltitude;
    }
    if (validateSensorValue(newAhtTemperature, AHT_TEMP_MIN, AHT_TEMP_MAX)) {
      ahtTemperature = newAhtTemperature;
    }
    if (validateSensorValue(newAhtHumidity, HUMIDITY_MIN, HUMIDITY_MAX)) {
      ahtHumidity = newAhtHumidity;
    }
    /*
    if (validateSensorValue(newAccelX, ACCEL_MIN, ACCEL_MAX)) {
      accelX = newAccelX;
    }
    if (validateSensorValue(newAccelY, ACCEL_MIN, ACCEL_MAX)) {
      accelY = newAccelY;
    }
    if (validateSensorValue(newAccelZ, ACCEL_MIN, ACCEL_MAX)) {
      accelZ = newAccelZ;
    }
    */
    if (validateSensorValue(newDustDensity, DUST_DENSITY_MIN, DUST_DENSITY_MAX)) {
      dustDensity = newDustDensity;
    }

    char dataString[250];
    snprintf(dataString, sizeof(dataString), "%0.2f,%0.2f,%0.2f,%0.2f,%0.2f,%0.2f,%0.2f,%0.2f,%0.2f",
             bmpTemperature, pressure, altitude, ahtTemperature, ahtHumidity, 0, 0, 0, dustDensity);
/*
    appendFile(SD, "/sensor_data.txt", dataString);
    appendFile(SD, "/sensor_data.txt", "\n");
    */
    Serial.print("Datos guardados: ");
    Serial.println(dataString);

    client.publish(mqtt_topic, dataString);
    Serial.print("Datos publicados: ");
    Serial.println(dataString);
  }
}

void appendFile(fs::FS &fs, const char *path, const char *message) {
  Serial.printf("Agregando al archivo: %s\n", path);

  File file = fs.open(path, FILE_APPEND);
  if (!file) {
    Serial.println("Error al abrir el archivo para agregar datos");
    return; 
  }
  if (file.print(message)) {
    Serial.println("Mensaje agregado");
  } else {
    Serial.println("Error al agregar al archivo");
  }
  file.close();
}

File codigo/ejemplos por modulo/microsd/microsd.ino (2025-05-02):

/*
 * Manejo de tarjeta MicroSD con SPI personalizado
 * Conexiones Heltec LoRa 32 V3:
 * - SCK  = GPIO35
 * - MISO = GPIO33
 * - MOSI = GPIO34
 * - CS   = GPIO36
 * 
 * Librería SD modificada para usar pines no estándar
 */

#include <SPI.h>
#include <SD.h>

// Configuración de pines SPI personalizados
const int SCK_PIN = 35;
const int MISO_PIN = 33;
const int MOSI_PIN = 34;
const int CS_PIN = 36;

// Objeto SPI personalizado
SPIClass customSPI(VSPI);

void setup() {
  Serial.begin(115200);
  while(!Serial); // Esperar conexión serial en placas con USB nativo

  Serial.println("\nProyecto Tzunun - Sistema de Archivos en MicroSD");
  
  // Configurar SPI con pines personalizados
  customSPI.begin(SCK_PIN, MISO_PIN, MOSI_PIN, CS_PIN);
  
  Serial.println("Inicializando tarjeta SD...");
  if(!SD.begin(CS_PIN, customSPI)) {
    Serial.println("¡Error al inicializar la tarjeta SD!");
    Serial.println("Verifica:");
    Serial.println("1. Conexiones de los pines");
    Serial.println("2. Formato de la tarjeta (FAT32)");
    Serial.println("3. Que la tarjeta esté insertada correctamente");
    return;
  }
  
  Serial.println("Tarjeta SD inicializada correctamente");
  
  // Crear archivo de prueba
  crearArchivo("/prueba.txt");
  
  // Leer archivo
  leerArchivo("/prueba.txt");
  
  // Listar directorio raíz
  listarDirectorio("/");
}

void loop() {
  // Nada en el loop para este ejemplo
}

// Función para crear/sobreescribir archivo
void crearArchivo(const char* filename) {
  File archivo = SD.open(filename, FILE_WRITE);
  
  if(archivo) {
    Serial.print("\nEscribiendo en archivo: ");
    Serial.println(filename);
    
    archivo.println("Datos de prueba - Proyecto Tzunun");
    archivo.println("Fecha: " + obtenerFecha());
    archivo.println("Hora: " + obtenerHora());
    archivo.println("Valor aleatorio: " + String(random(100)));
    
    archivo.close();
    Serial.println("Escritura completada");
  } else {
    Serial.print("Error al abrir ");
    Serial.println(filename);
  }
}

// Función para leer archivo
void leerArchivo(const char* filename) {
  File archivo = SD.open(filename);
  
  if(archivo) {
    Serial.print("\nLeyendo archivo: ");
    Serial.println(filename);
    
    while(archivo.available()) {
      Serial.write(archivo.read());
    }
    archivo.close();
  } else {
    Serial.print("Error al leer ");
    Serial.println(filename);
  }
}

// Función para listar directorios
void listarDirectorio(const char* dirname) {
  Serial.print("\nContenido del directorio: ");
  Serial.println(dirname);

  File root = SD.open(dirname);
  
  if(!root) {
    Serial.println("Error al abrir directorio");
    return;
  }
  
  if(!root.isDirectory()) {
    Serial.println("No es un directorio");
    return;
  }

  File entry = root.openNextFile();
  while(entry) {
    if(entry.isDirectory()) {
      Serial.print("DIR : ");
      Serial.println(entry.name());
    } else {
      Serial.print("FILE: ");
      Serial.print(entry.name());
      Serial.print("\tTAMAÑO: ");
      Serial.println(entry.size());
    }
    entry = root.openNextFile();
  }
  
  root.close();
}

// Función para obtener fecha ficticia (implementar RTC para precisión)
String obtenerFecha() {
  return "2023-11-15";
}

// Función para obtener hora ficticia
String obtenerHora() {
  return "14:30:00";
}
